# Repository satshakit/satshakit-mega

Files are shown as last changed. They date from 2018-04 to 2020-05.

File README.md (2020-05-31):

<div align="center"><h1 style="font-family: courier;" align="center">satshakit-mega</h1></div>
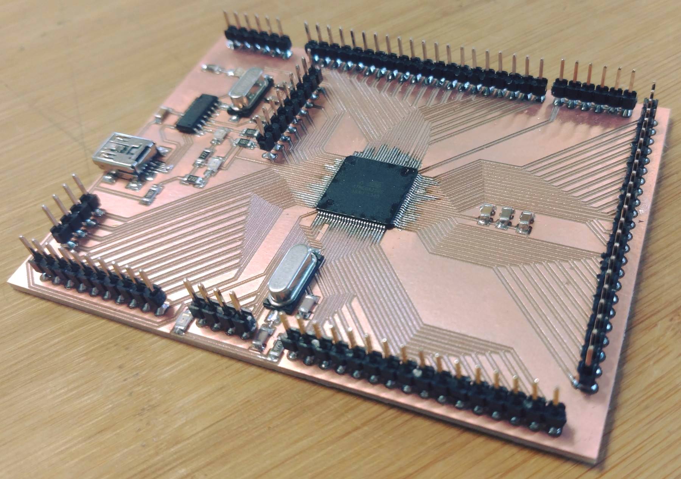
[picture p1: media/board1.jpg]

<div align="center"><i>An open source & fabbable ATMega2560 based microcontroller board.</i></div>

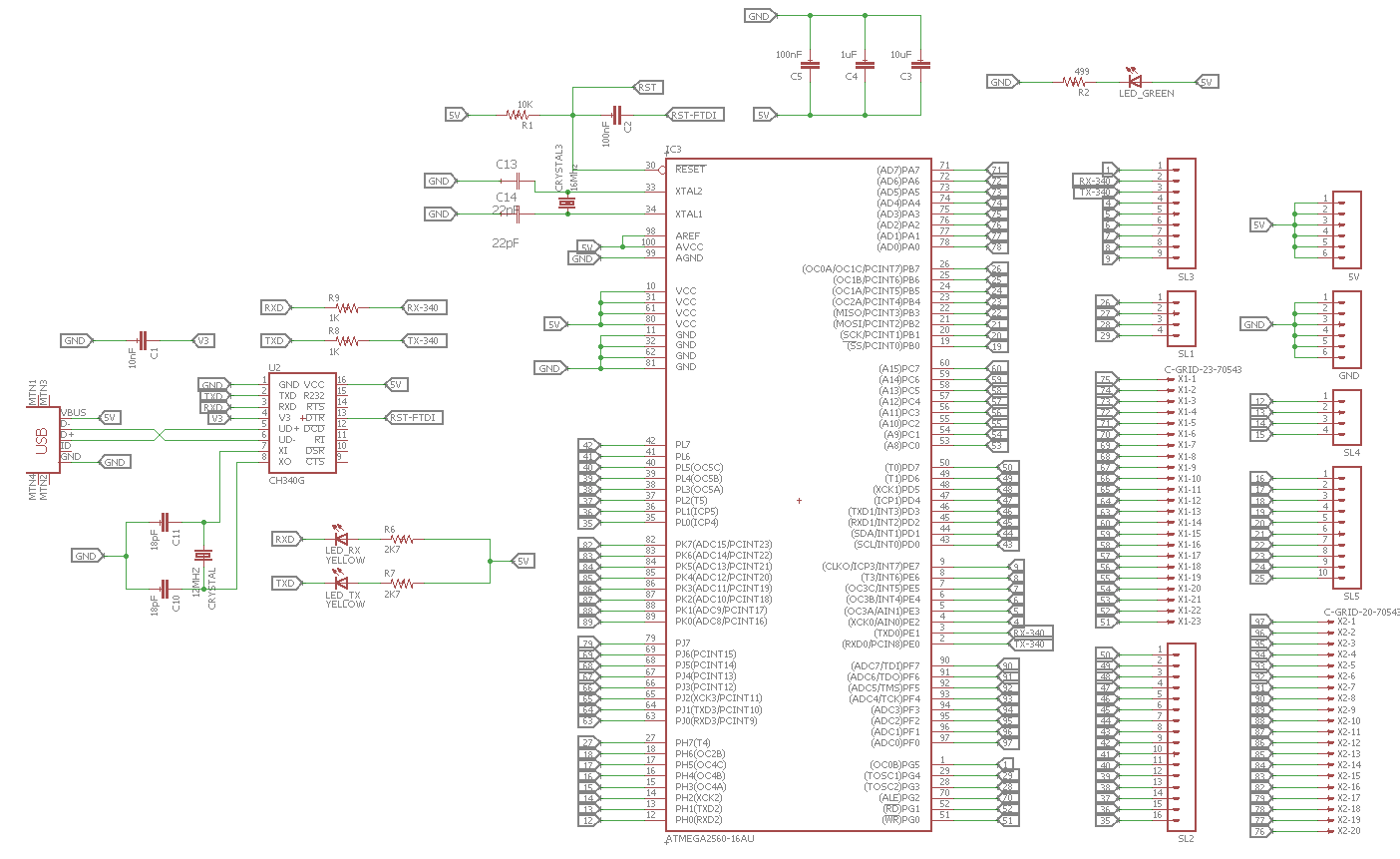
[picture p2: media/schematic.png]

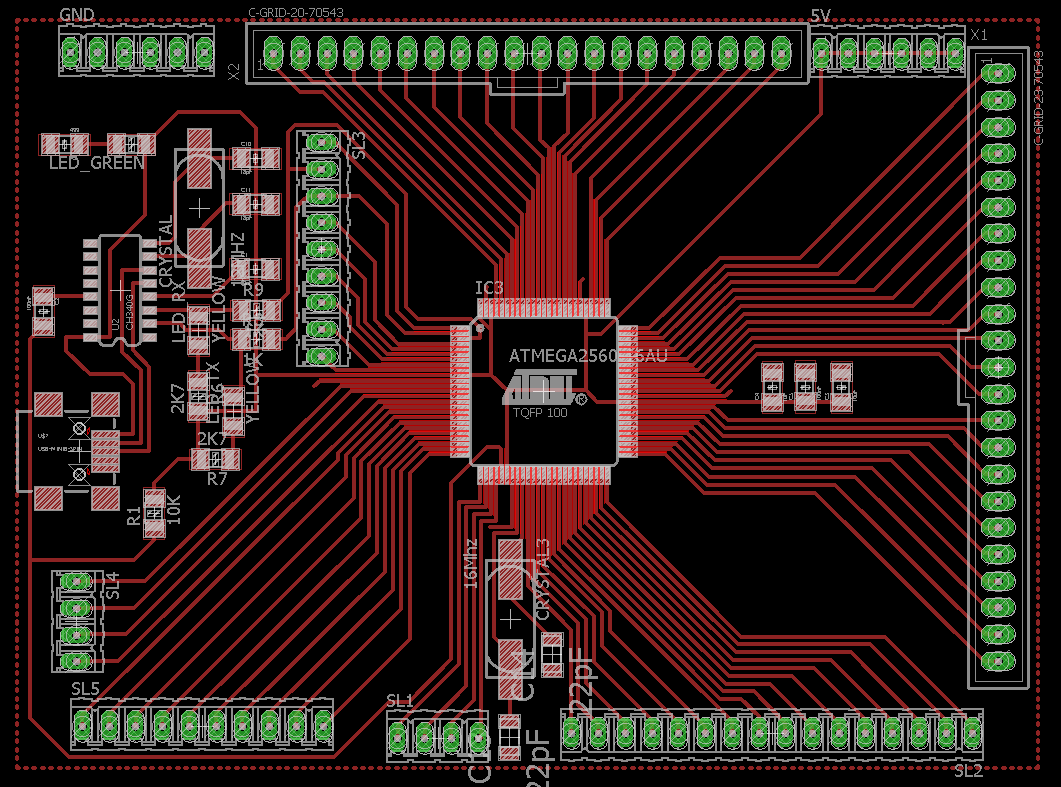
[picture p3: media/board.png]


License
--
This work is licensed under the terms of the open source license: Creative Commons Attribution-ShareAlike 4.0 International ([CC BY-SA 4.0](https://creativecommons.org/licenses/by-sa/4.0/)).

Disclaimer  
--

<div class="align-justify">
This hardware/software is provided "as is", and you use the hardware/software at your own risk. Under no circumstances shall any author be liable for direct, indirect, special, incidental, or consequential damages resulting from the use, misuse, or inability to use this hardware/software, even if the authors have been advised of the possibility of such damages.</div>

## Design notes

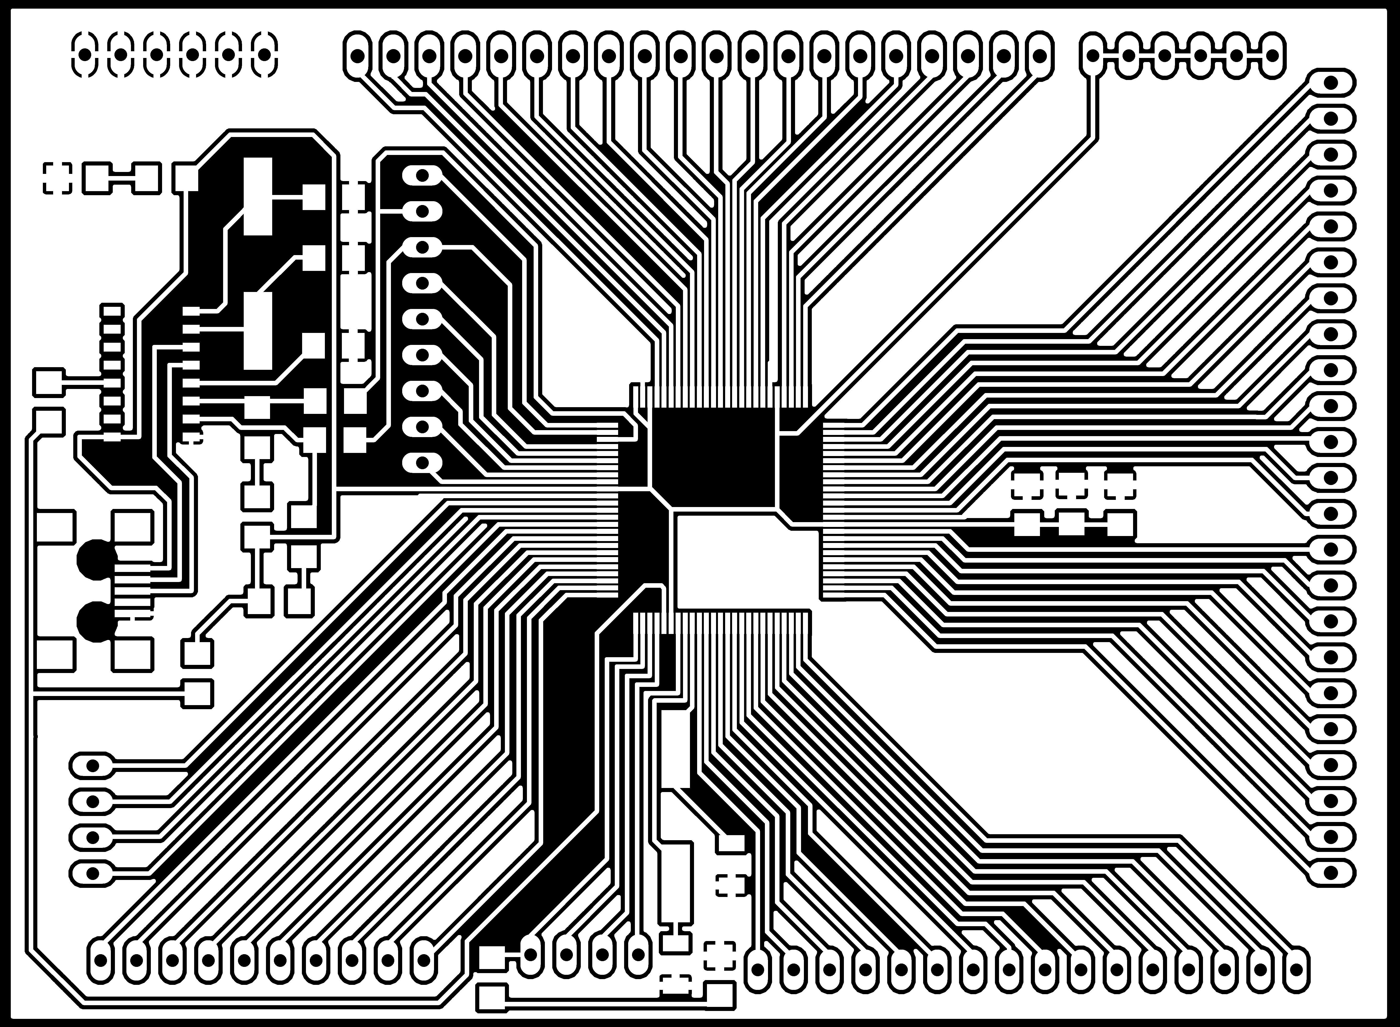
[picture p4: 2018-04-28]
media/internal.png

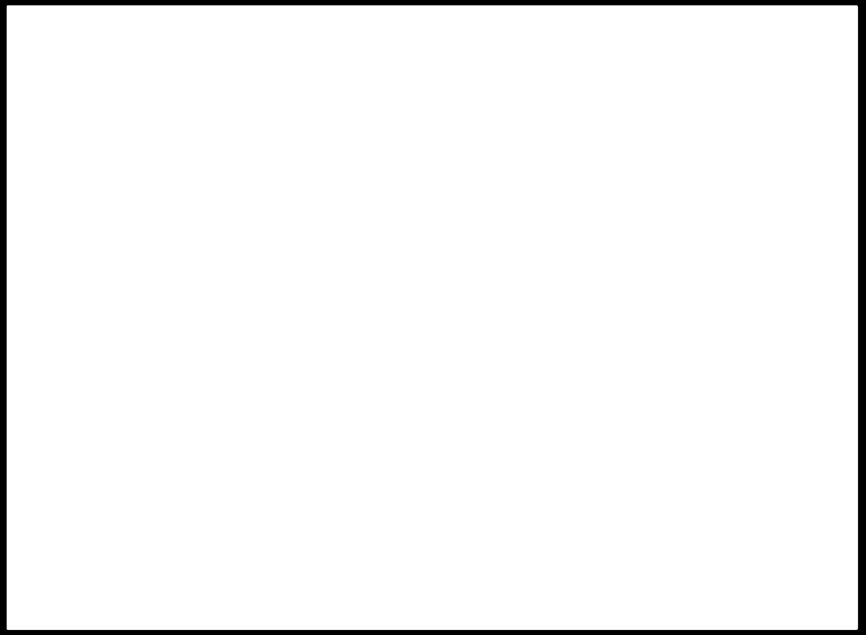
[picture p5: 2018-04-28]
media/external.png

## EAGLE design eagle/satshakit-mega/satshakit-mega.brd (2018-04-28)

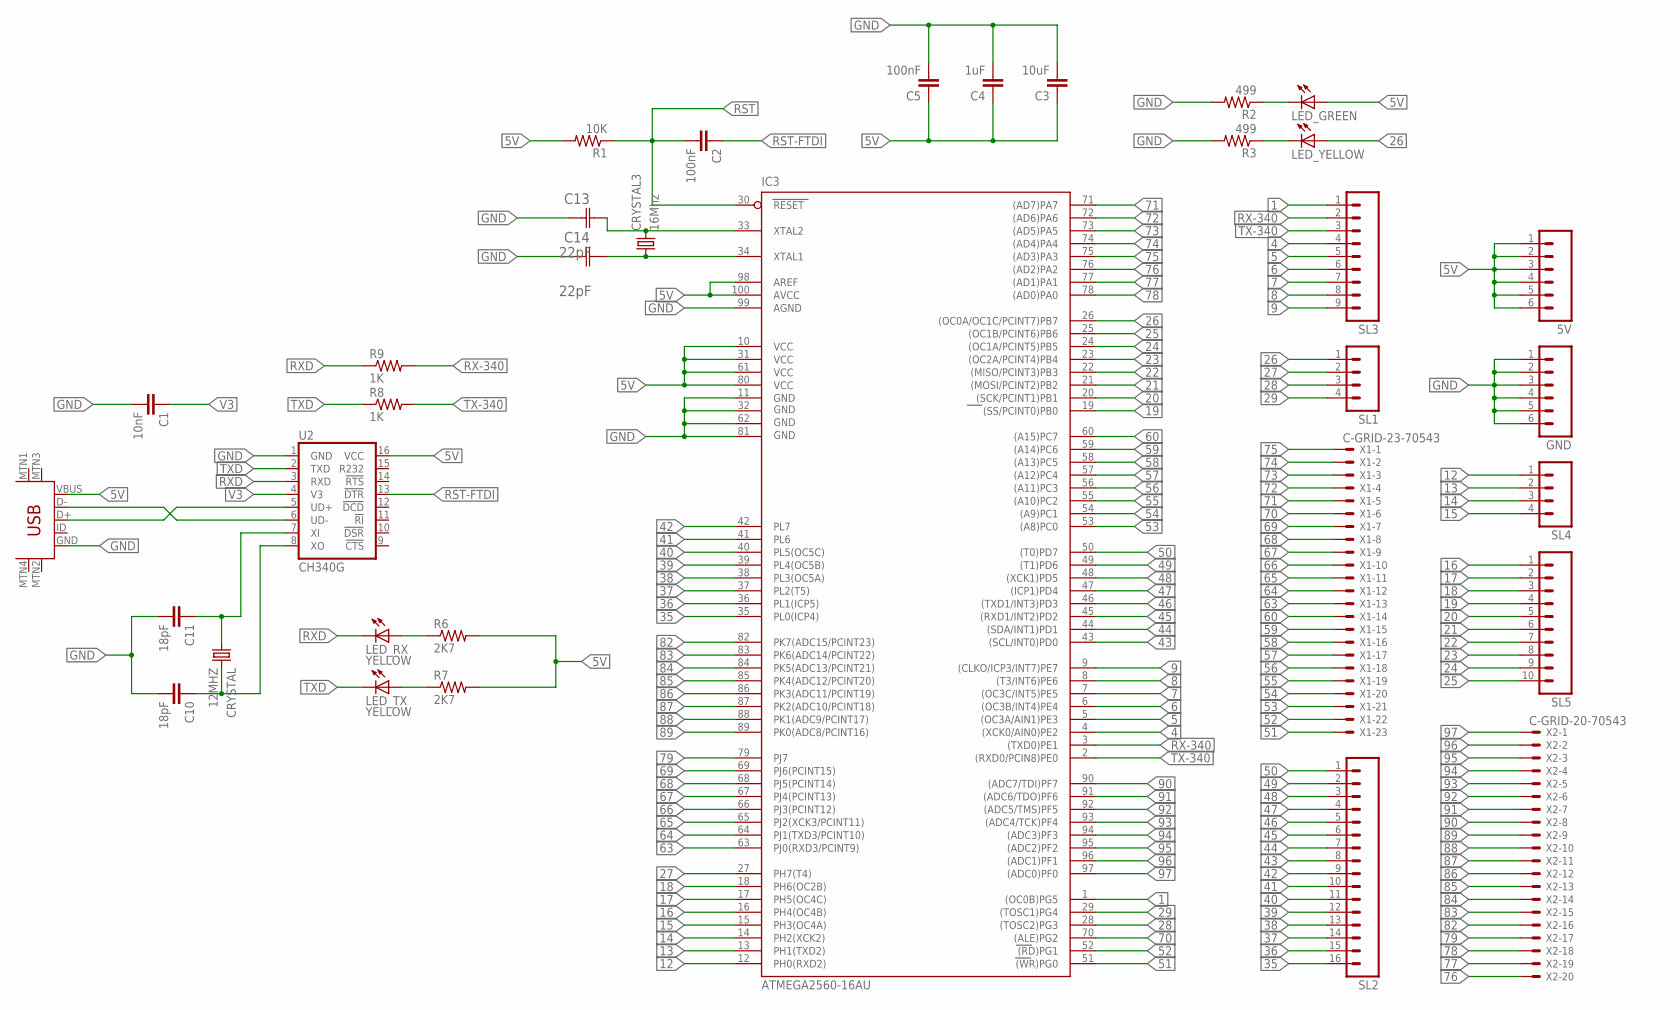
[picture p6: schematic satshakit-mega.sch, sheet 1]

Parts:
5V: M06; 06P
C1: 10nF; 1206
C2, C5: 100nF; 1206
C3: 10uF; 1206
C4: 1uF; 1206
C10, C11: 18pF; 1206
C13, C14: 22pF; CAPC3216X178N
CRYSTAL: 12MHZ; CSM-7X-DU
CRYSTAL3: 16Mhz; CSM-7X-DU
GND: M06; 06P
IC3: ATMEGA2560-16AU; TQFP100
LED_GREEN: LED1206; 1206
LED_RX: YELLOW; LED1206
LED_TX: YELLOW; LED1206
LED_YELLOW: LED1206; 1206
R1: 10K; R1206
R2, R3: 499; 1206
R6, R7: 2K7; R1206
R8, R9: 1K; R1206
SL1, SL4: M04; 04P
SL2: M16; 16P
SL3: M09; 09P
SL5: M10; 10P
U2: CH340G; SO016
U$7: USB-MINIB-5PIN; USB-MINIB
X1: C-GRID-23-70543; 70543-23
X2: C-GRID-20-70543; 70543-20

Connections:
1: IC3.1 ((OC0B)PG5), SL3.1
4: IC3.4 ((XCK0/AIN0)PE2), SL3.4
5: IC3.5 ((OC3A/AIN1)PE3), SL3.5
5V: 5V.1, 5V.2, 5V.3, 5V.4, 5V.5, 5V.6, C3.1, C4.1, C5.1, IC3.10 (VCC), IC3.31 (VCC1), IC3.61 (VCC2), IC3.80 (VCC3), IC3.98 (AREF), IC3.100 (AVCC), LED_GREEN.1 (A), R1.2, R6.2, R7.2, U2.16 (VCC), U$7.VBUS
6: IC3.6 ((OC3B/INT4)PE4), SL3.6
7: IC3.7 ((OC3C/INT5)PE5), SL3.7
8: IC3.8 ((T3/INT6)PE6), SL3.8
9: IC3.9 ((CLKO/ICP3/INT7)PE7), SL3.9
12: IC3.12 (PH0(RXD2)), SL4.1
13: IC3.13 (PH1(TXD2)), SL4.2
14: IC3.14 (PH2(XCK2)), SL4.3
15: IC3.15 (PH3(OC4A)), SL4.4
16: IC3.16 (PH4(OC4B)), SL5.1
17: IC3.17 (PH5(OC4C)), SL5.2
18: IC3.18 (PH6(OC2B)), SL5.3
19: IC3.19 ((SS/PCINT0)PB0), SL5.4
20: IC3.20 ((SCK/PCINT1)PB1), SL5.5
21: IC3.21 ((MOSI/PCINT2)PB2), SL5.6
22: IC3.22 ((MISO/PCINT3)PB3), SL5.7
23: IC3.23 ((OC2A/PCINT4)PB4), SL5.8
24: IC3.24 ((OC1A/PCINT5)PB5), SL5.9
25: IC3.25 ((OC1B/PCINT6)PB6), SL5.10
26: IC3.26 ((OC0A/OC1C/PCINT7)PB7), LED_YELLOW.1 (A), SL1.1
27: IC3.27 (PH7(T4)), SL1.2
28: IC3.28 ((TOSC2)PG3), SL1.3
29: IC3.29 ((TOSC1)PG4), SL1.4
35: IC3.35 (PL0(ICP4)), SL2.16
36: IC3.36 (PL1(ICP5)), SL2.15
37: IC3.37 (PL2(T5)), SL2.14
38: IC3.38 (PL3(OC5A)), SL2.13
39: IC3.39 (PL4(OC5B)), SL2.12
40: IC3.40 (PL5(OC5C)), SL2.11
41: IC3.41 (PL6), SL2.10
42: IC3.42 (PL7), SL2.9
43: IC3.43 ((SCL/INT0)PD0), SL2.8
44: IC3.44 ((SDA/INT1)PD1), SL2.7
45: IC3.45 ((RXD1/INT2)PD2), SL2.6
46: IC3.46 ((TXD1/INT3)PD3), SL2.5
47: IC3.47 ((ICP1)PD4), SL2.4
48: IC3.48 ((XCK1)PD5), SL2.3
49: IC3.49 ((T1)PD6), SL2.2
50: IC3.50 ((T0)PD7), SL2.1
51: IC3.51 ((WR)PG0), X1.23
52: IC3.52 ((RD)PG1), X1.22
53: IC3.53 ((A8)PC0), X1.21
54: IC3.54 ((A9)PC1), X1.20
55: IC3.55 ((A10)PC2), X1.19
56: IC3.56 ((A11)PC3), X1.18
57: IC3.57 ((A12)PC4), X1.17
58: IC3.58 ((A13)PC5), X1.16
59: IC3.59 ((A14)PC6), X1.15
60: IC3.60 ((A15)PC7), X1.14
63: IC3.63 (PJ0(RXD3/PCINT9)), X1.13
64: IC3.64 (PJ1(TXD3/PCINT10)), X1.12
65: IC3.65 (PJ2(XCK3/PCINT11)), X1.11
66: IC3.66 (PJ3(PCINT12)), X1.10
67: IC3.67 (PJ4(PCINT13)), X1.9
68: IC3.68 (PJ5(PCINT14)), X1.8
69: IC3.69 (PJ6(PCINT15)), X1.7
70: IC3.70 ((ALE)PG2), X1.6
71: IC3.71 ((AD7)PA7), X1.5
72: IC3.72 ((AD6)PA6), X1.4
73: IC3.73 ((AD5)PA5), X1.3
74: IC3.74 ((AD4)PA4), X1.2
75: IC3.75 ((AD3)PA3), X1.1
76: IC3.76 ((AD2)PA2), X2.20
77: IC3.77 ((AD1)PA1), X2.19
78: IC3.78 ((AD0)PA0), X2.18
79: IC3.79 (PJ7), X2.17
82: IC3.82 (PK7(ADC15/PCINT23)), X2.16
83: IC3.83 (PK6(ADC14/PCINT22)), X2.15
84: IC3.84 (PK5(ADC13/PCINT21)), X2.14
85: IC3.85 (PK4(ADC12/PCINT20)), X2.13
86: IC3.86 (PK3(ADC11/PCINT19)), X2.12
87: IC3.87 (PK2(ADC10/PCINT18)), X2.11
88: IC3.88 (PK1(ADC9/PCINT17)), X2.10
89: IC3.89 (PK0(ADC8/PCINT16)), X2.9
90: IC3.90 ((ADC7/TDI)PF7), X2.8
91: IC3.91 ((ADC6/TDO)PF6), X2.7
92: IC3.92 ((ADC5/TMS)PF5), X2.6
93: IC3.93 ((ADC4/TCK)PF4), X2.5
94: IC3.94 ((ADC3)PF3), X2.4
95: IC3.95 ((ADC2)PF2), X2.3
96: IC3.96 ((ADC1)PF1), X2.2
97: IC3.97 ((ADC0)PF0), X2.1
GND: C1.2, C3.2, C4.2, C5.2, C10.2, C11.2, C13.1 (C1), C14.1 (C1), GND.1, GND.2, GND.3, GND.4, GND.5, GND.6, IC3.11 (GND), IC3.32 (GND1), IC3.62 (GND2), IC3.81 (GND3), IC3.99 (AGND), R2.2, R3.2, U2.1 (GND), U$7.GND
unnamed: U2.5 (UD+), U$7.D+
unnamed: LED_RX.1 (A), R6.1
unnamed: U2.6 (UD-), U$7.D-
unnamed: C14.2 (C2), CRYSTAL3.1, IC3.34 (XTAL1)
unnamed: C13.2 (C2), CRYSTAL3.2, IC3.33 (XTAL2)
unnamed: LED_YELLOW.2 (C), R3.1
unnamed: LED_TX.1 (A), R7.1
unnamed: LED_GREEN.2 (C), R2.1
OSC_IN: C10.1, CRYSTAL.2, U2.8 (XO)
OSC_OUT: C11.1, CRYSTAL.1, U2.7 (XI)
RST: C2.2, IC3.30 (RESET), R1.1
RST-FTDI: C2.1, U2.13 (!DTR)
RX-340: IC3.3 ((TXD0)PE1), R9.2, SL3.2
RXD: LED_RX.2 (C), R9.1, U2.3 (RXD)
TX-340: IC3.2 ((RXD0/PCIN8)PE0), R8.2, SL3.3
TXD: LED_TX.2 (C), R8.1, U2.2 (TXD)
V3: C1.1, U2.4 (V3)

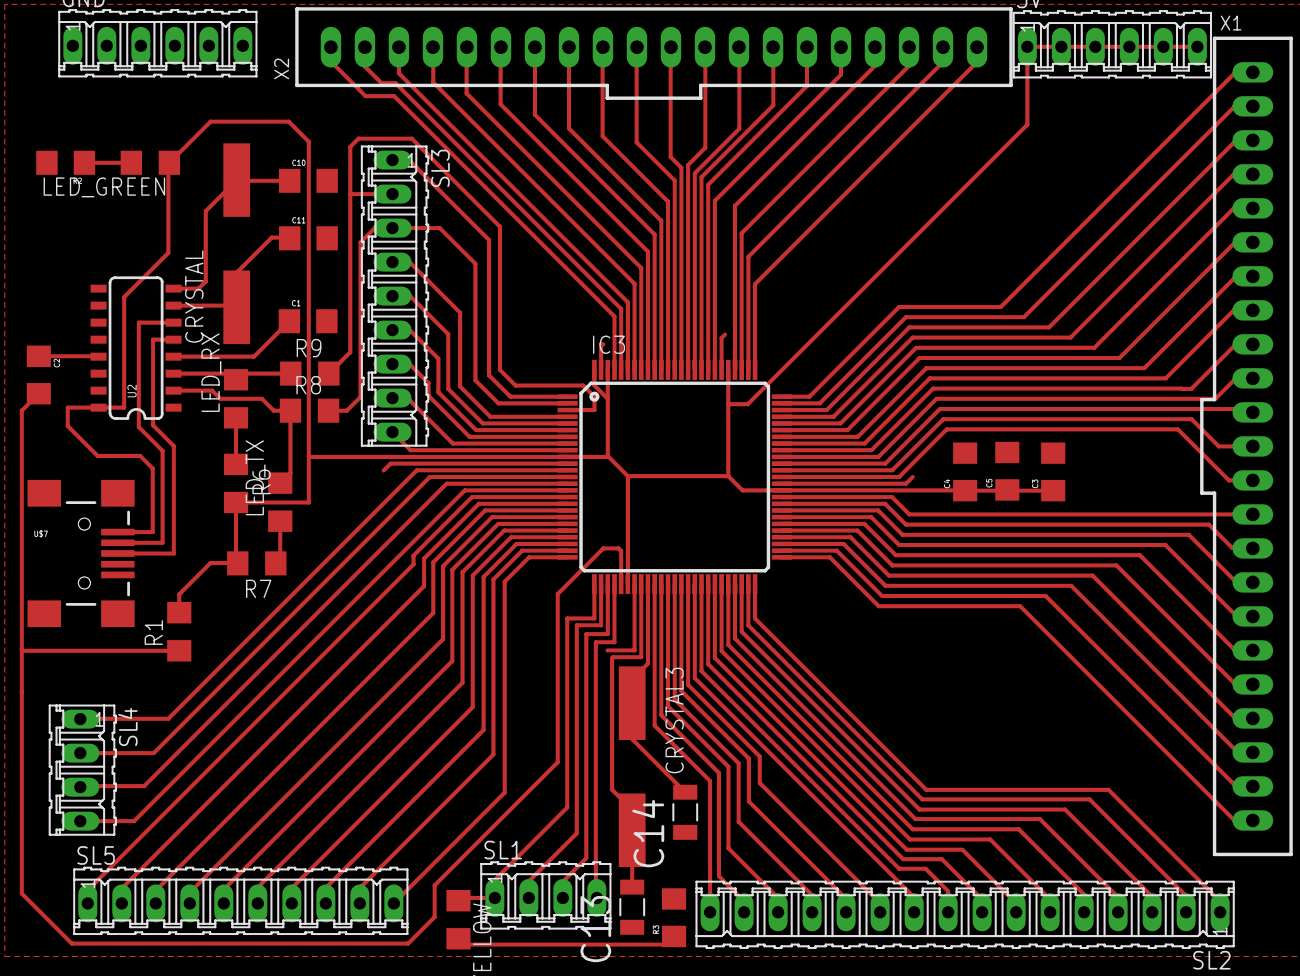
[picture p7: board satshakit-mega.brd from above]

Board: 2 copper layers, 34 parts (0 on the bottom side), 103 nets.

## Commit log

2018-04-21 added default led
    [satshakit-mega.brd, satshakit-mega.sch]
2018-04-28 slighty change one trace
    [satshakit-mega.brd]
2018-04-28 added milling images

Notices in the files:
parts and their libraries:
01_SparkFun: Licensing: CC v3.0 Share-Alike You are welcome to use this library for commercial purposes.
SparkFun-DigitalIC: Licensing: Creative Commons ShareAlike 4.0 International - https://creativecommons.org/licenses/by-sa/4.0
